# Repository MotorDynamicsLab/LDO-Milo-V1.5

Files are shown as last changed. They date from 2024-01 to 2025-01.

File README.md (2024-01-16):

# LDO Milo V1.5 Kit
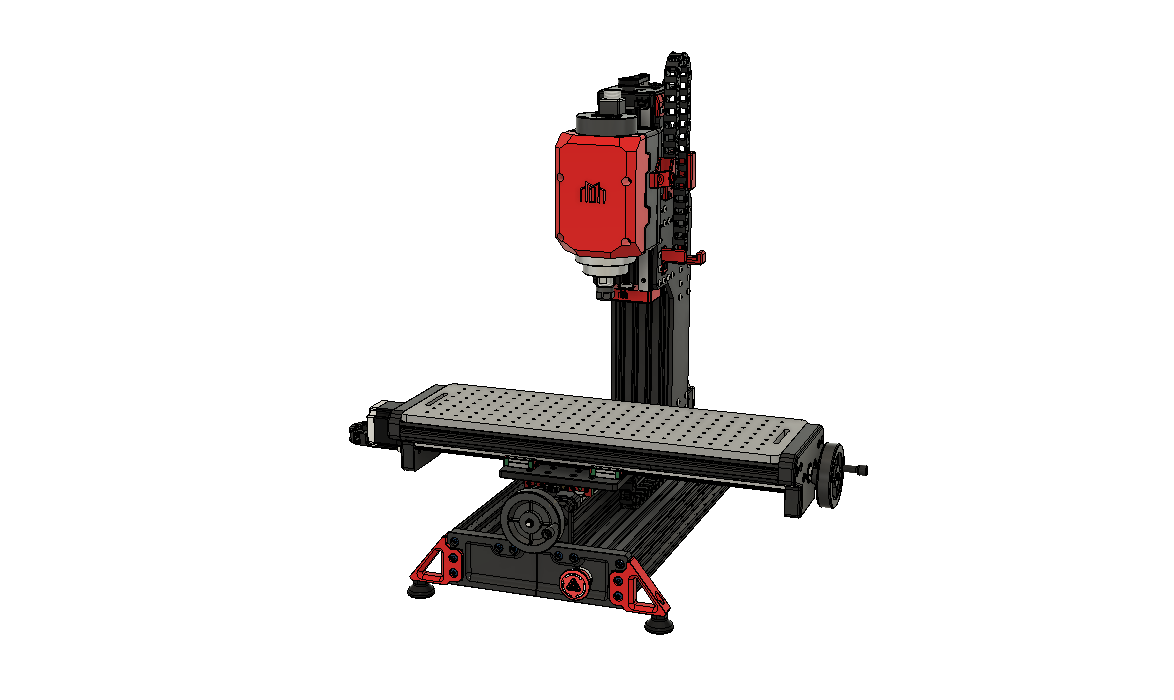
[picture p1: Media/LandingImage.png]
Banner landing image
  

This repository contains supplementary information/configuration/3d models for the LDO Milo V1.5 Kit.

We would thank the Millennium Machines Development team for all their hard work in bringing this open source CNC mill to the community. The github repository for Milo V1.5 can be found [here](https://github.com/MillenniumMachines/Milo-v1.5)  

This repo contains both original and derivative works from the Milo V1.5 project, which is licensed GPLv3. This repo therefore is also licensed under the terms of the GNU Public License, verison 3.

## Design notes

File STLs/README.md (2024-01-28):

Please refer to [PRINTED_PARTS.md](PRINTED_PARTS.md) for the full list of printed parts required for our LDO Milo Kit

## Inlet Skirt 1.0mm
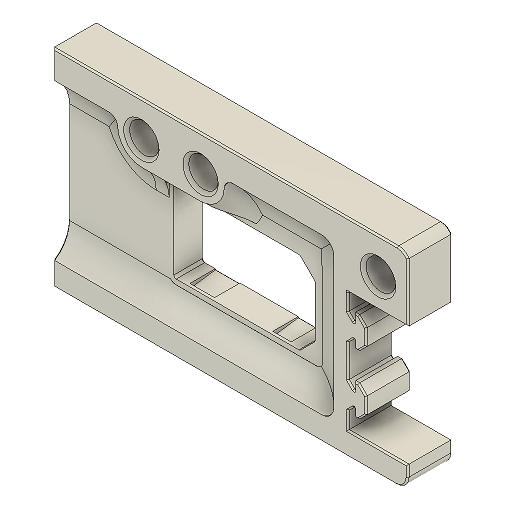
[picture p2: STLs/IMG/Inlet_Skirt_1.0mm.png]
  
This part replaces the `plug_panel` part from the official [Milo V1.5 repo](https://github.com/MillenniumMachines/Milo-v1.5/tree/main/STL%20Files). It adapts specifically to 1.0mm AC inlets for a better fit.

## Fly CDY V3 Mount
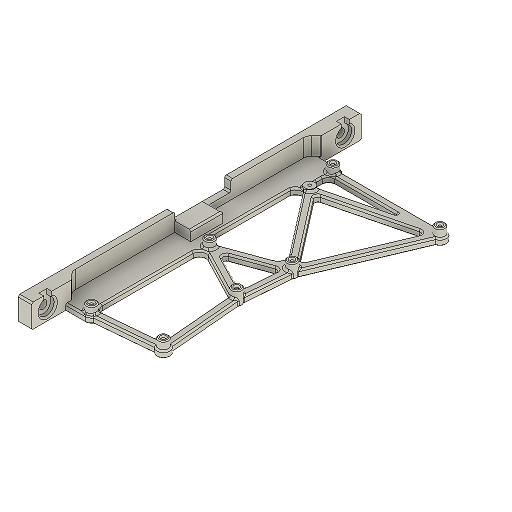
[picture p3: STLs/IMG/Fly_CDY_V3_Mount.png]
  
This is an LDO designed mount for the FLY CDY V3 mainboard provided in the kit. It replaces the original printed part and allows for easy insertion of the SD card. 

## I/O Expander Mount
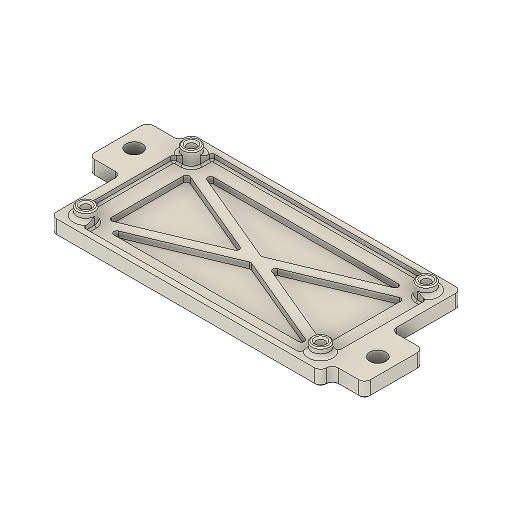
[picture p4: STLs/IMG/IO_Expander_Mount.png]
  
This is a printed mount for the LDO I/O expansion board included in the kit. The expansion board allows the mainboard to control the spindle VFD.

## I/O Expander Mount (For DIN Rails)
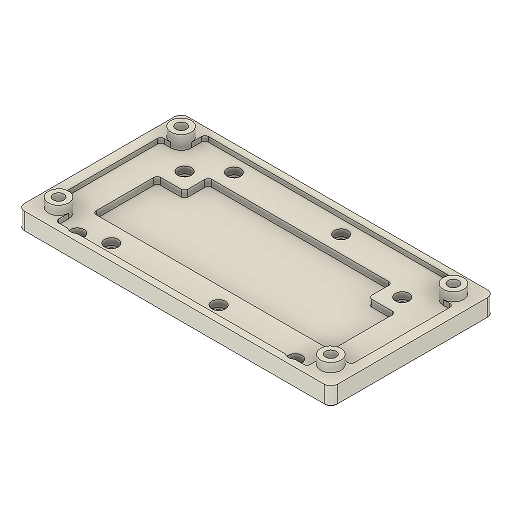
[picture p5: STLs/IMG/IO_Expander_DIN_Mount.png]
  
This printed part is for the same I/O expansion board as described above, it is specifically used for mounting on DIN rails for the CASA mod.

## LMF350-UH PSU Mount
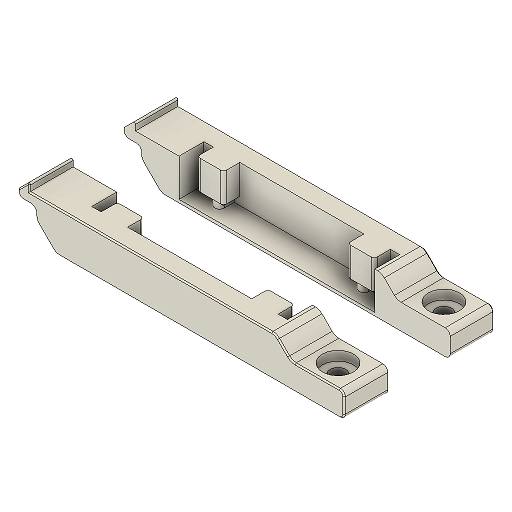
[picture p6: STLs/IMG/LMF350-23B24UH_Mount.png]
  
The LMF350-UH series compact power supplied in the kit uses these mounting brackets. 

## LDO Handwheel
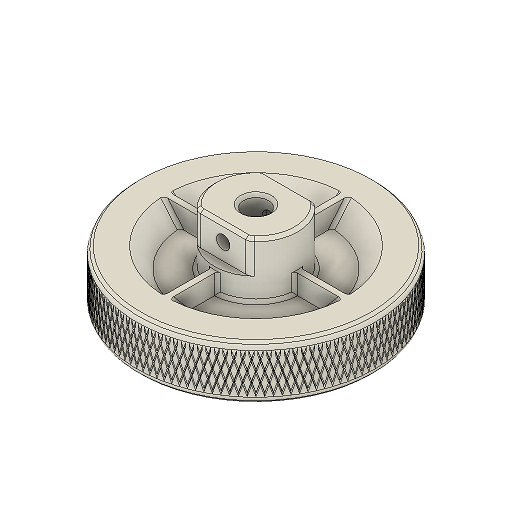
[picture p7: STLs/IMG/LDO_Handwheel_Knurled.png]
  
This is an optional handle wheel design which features knurling. 

## LDO Handwheel (Smooth)
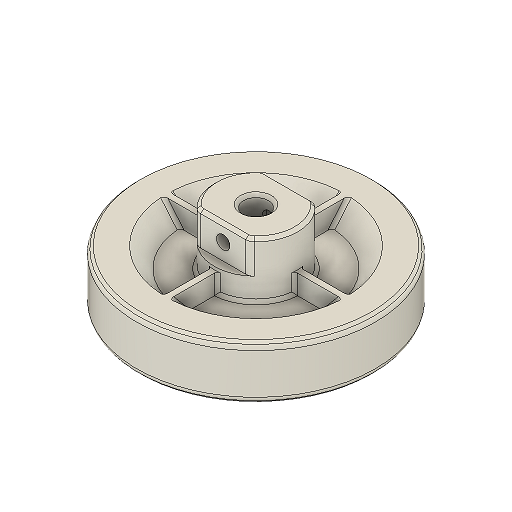
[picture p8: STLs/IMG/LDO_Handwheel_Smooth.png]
  
This is the same handwheel as above but omits knurling.

## X Motor Mount
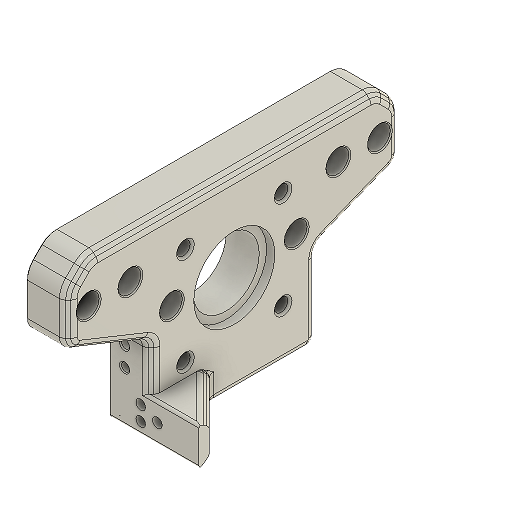
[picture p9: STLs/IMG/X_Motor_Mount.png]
  
This X Motor mount features a small tab that prevents the X drag chain from flopping.

## FMJ Z Chain Backer
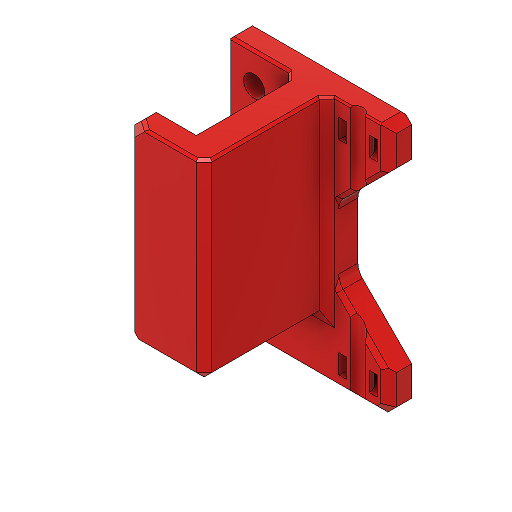
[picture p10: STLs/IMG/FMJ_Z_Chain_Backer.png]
  
This drag chain backer mounts on the FMJ plate. It also features anchor points for cable ties.

## Z Drag Chain Mount B
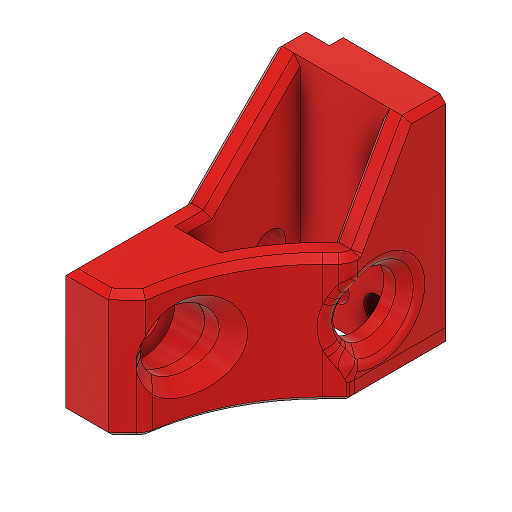
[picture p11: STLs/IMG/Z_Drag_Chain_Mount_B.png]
  
This drag chain mount replaces the original Z Drag Chain Mount B, it helps prevent flopping.

## Z Top Cable Tie Anchor
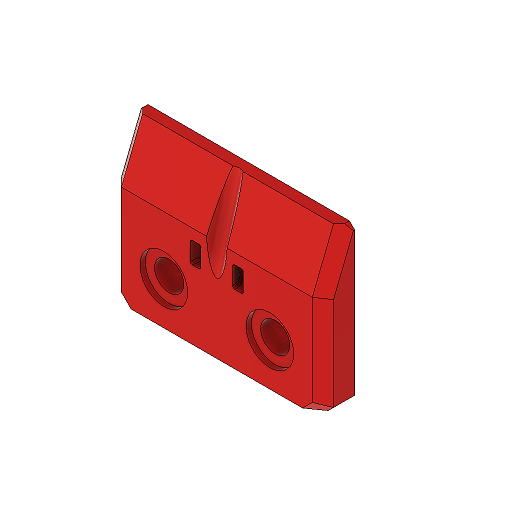
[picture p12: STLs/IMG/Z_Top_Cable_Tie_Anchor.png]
  
This optional printed part adds a cable tie anchor at the top of the main column.

## Rear Cable Cover
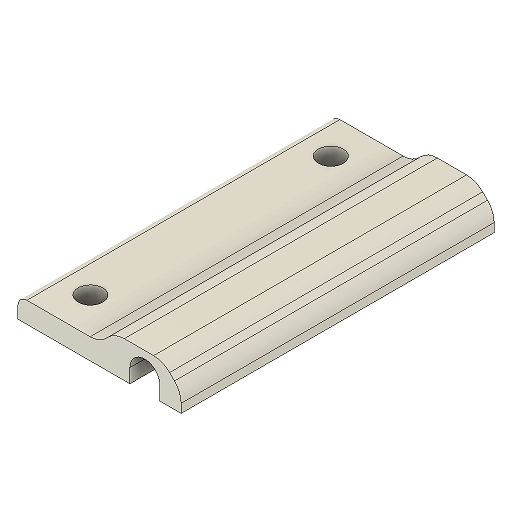
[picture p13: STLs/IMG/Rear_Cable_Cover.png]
  
This optional printed part helps hold down the X and Y cables onto the electronics table.

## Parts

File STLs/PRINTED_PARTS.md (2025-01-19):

# Printed Parts List
This repo contains all of the parts required for the LDO kit.  We have excluded some parts from the original repository that are not needed for our kit and
have added or modified parts as denoted in the "LDO Version" column.  Parts with multiple variations are interchangeable and only one version is needed.

## Print Quality (Strength)
These setting assume that parts will be printed with a 0.4mm nozzle and 0.2mm layer height and result in a 1.6mm wall thickness

- Infill 40%
- Wall Loops 4
- Top/Bottom Layers 8

## Filename Convention

Filenames with one of the following denotes a recommended filament color otherwise use your primary color 
- [a] - accent
- [o] - opaque 
- [c] - clear

(Note: This repo may not use all of these)
            
Filenames with a [v] denote a part has multiple variations
- [v] - variation

Filenames with a [##] denotes specific wall thickness instead of the default
- i.e. [24] 2.4mm thickness with a 0.4 mm nozzle and 0.2 layer height
- Walls Loops 2.4/0.4 = 6
- Top/Bottom Layers 2.4/0.2 = 12

Filenames will include x# denotes how many copies you will need
- i.e. Test x3.stl will require 3 copies
%5Ba%5D
Filenames with "LDO" denotes that we have modified the original part or it's specific to the LDO kit
# Electronics Table
|File|Directory|Qty|Color|Strength|LDO Version|Variations|
|---|---|---|---|---|---|---|
|<a href="Electronics Table/Cable Channel Cover x1.stl">Cable Channel Cover x1.stl</a>|Electronics Table|1|Primary|1.6mm|||
|<a href="Electronics Table/Cable Channel x1.stl">Cable Channel x1.stl</a>|Electronics Table|1|Primary|1.6mm|||
|<a href="Electronics Table/IO Expander DIN Mount  x1_LDO.stl">IO Expander DIN Mount  x1_LDO.stl</a>|Electronics Table|1|Primary|1.6mm|X||
|<a href="Electronics Table/IO Expander Mount  x1_LDO.stl">IO Expander Mount  x1_LDO.stl</a>|Electronics Table|1|Primary|1.6mm|X||
|<a href="Electronics Table/Mainboard Mount x1_LDO.stl">Mainboard Mount x1_LDO.stl</a>|Electronics Table|1|Primary|1.6mm|X||
|<a href="Electronics Table/PSU Mounting Brackets  x1_LDO.stl">PSU Mounting Brackets  x1_LDO.stl</a>|Electronics Table|1|Primary|1.6mm|X||
|<a href="Electronics Table/Rear Skirt A x1.stl">Rear Skirt A x1.stl</a>|Electronics Table|1|Primary|1.6mm|||
|<a href="Electronics Table/Rear Skirt B x1.stl">Rear Skirt B x1.stl</a>|Electronics Table|1|Primary|1.6mm|||
|<a href="Electronics Table/Skirt Front A Solid x1.stl">Skirt Front A Solid x1.stl</a>|Electronics Table|1|Primary|1.6mm|||
|<a href="Electronics Table/Skirt Front B E-Stop x1.stl">Skirt Front B E-Stop x1.stl</a>|Electronics Table|1|Primary|1.6mm|||
|<a href="Electronics Table/TPU Feet x4.stl">TPU Feet x4.stl</a>|Electronics Table|1|Primary|1.6mm|||
|<a href="Electronics Table/WAGO Mount x1_LDO.stl">WAGO Mount x1_LDO.stl</a>|Electronics Table|1|Primary|1.6mm|X||
|<a href="Electronics Table/%5Ba%5D Table Bolt Down Bracket A x2_LDO.stl">[a] Table Bolt Down Bracket A x2_LDO.stl</a>|Electronics Table|2|Accent|1.6mm|X||
|<a href="Electronics Table/%5Ba%5D Table Bolt Down Bracket B x2_LDO.stl">[a] Table Bolt Down Bracket B x2_LDO.stl</a>|Electronics Table|2|Accent|1.6mm|X||
# Minimill Main
|File|Directory|Qty|Color|Strength|LDO Version|Variations|
|---|---|---|---|---|---|---|
|<a href="Minimill Main/Continental Breakfast Mount x2_LDO.stl">Continental Breakfast Mount x2_LDO.stl</a>|Minimill Main|2|Primary|1.6mm|X||
|<a href="Minimill Main/Millenium Maker Coin.stl">Millenium Maker Coin.stl</a>|Minimill Main|1|Primary|1.6mm|||
|<a href="Minimill Main/Toolsetter x1_LDO.stl">Toolsetter x1_LDO.stl</a>|Minimill Main|1|Primary|1.6mm|X||
# Cable Chain Mounts
|File|Directory|Qty|Color|Strength|LDO Version|Variations|
|---|---|---|---|---|---|---|
|<a href="Minimill Main/Cable Chain Mounts/Rear Cable Cover x1_LDO.stl">Rear Cable Cover x1_LDO.stl</a>|Minimill Main/Cable Chain Mounts|1|Primary|1.6mm|X||
|<a href="Minimill Main/Cable Chain Mounts/%5Ba%5D XY Drag Chain Transition x1.stl">[a] XY Drag Chain Transition x1.stl</a>|Minimill Main/Cable Chain Mounts|1|Accent|1.6mm||| [a] XY Drag Chain Transition x1.stl
|<a href="Minimill Main/Cable Chain Mounts/%5Ba%5D Y Drag Chain Mount x1.stl">[a] Y Drag Chain Mount x1.stl</a>|Minimill Main/Cable Chain Mounts|1|Accent|1.6mm|||
|<a href="Minimill Main/Cable Chain Mounts/%5Ba%5D Z Axis Cable Chain Backer x1_LDO.stl">[a] Z Axis Cable Chain Backer x1_LDO.stl</a>|Minimill Main/Cable Chain Mounts|1|Accent|1.6mm|X||
|<a href="Minimill Main/Cable Chain Mounts/%5Ba%5D Z Cable Redirect Hook x1.stl">[a] Z Cable Redirect Hook x1.stl</a>|Minimill Main/Cable Chain Mounts|1|Accent|1.6mm|||
|<a href="Minimill Main/Cable Chain Mounts/%5Ba%5D Z Drag Chain Mount A x1_LDO.stl">[a] Z Drag Chain Mount A x1_LDO.stl</a>|Minimill Main/Cable Chain Mounts|1|Accent|1.6mm|X||
|<a href="Minimill Main/Cable Chain Mounts/%5Ba%5D Z Drag Chain Mount B x1_LDO.stl">[a] Z Drag Chain Mount B x1_LDO.stl</a>|Minimill Main/Cable Chain Mounts|1|Accent|1.6mm|X||
|<a href="Minimill Main/Cable Chain Mounts/%5Ba%5D Z Top Cable Tie Anchor_LDO.stl">[a] Z Top Cable Tie Anchor_LDO.stl</a>|Minimill Main/Cable Chain Mounts|1|Accent|1.6mm|X||
# Hand Wheels
|File|Directory|Qty|Color|Strength|LDO Version|Variations|
|---|---|---|---|---|---|---|
|<a href="Minimill Main/Hand Wheels/Handwheel Handle x2.stl">Handwheel Handle x2.stl</a>|Minimill Main/Hand Wheels|1|Primary|1.6mm|||
|<a href="Minimill Main/Hand Wheels/%5Bv%5D Handwheel Body Knurled x2_LDO.stl">[v] Handwheel Body Knurled x2_LDO.stl</a>|Minimill Main/Hand Wheels|2|Primary|1.6mm|X|X|
|<a href="Minimill Main/Hand Wheels/%5Bv%5D Handwheel Body x2_LDO.stl">[v] Handwheel Body x2_LDO.stl</a>|Minimill Main/Hand Wheels|2|Primary|1.6mm|X|X|
# Main Column
|File|Directory|Qty|Color|Strength|LDO Version|Variations|
|---|---|---|---|---|---|---|
|<a href="Minimill Main/Main Column/Ballast Box x1.stl">Ballast Box x1.stl</a>|Minimill Main/Main Column|1|Primary|1.6mm|||
|<a href="Minimill Main/Main Column/Ballast Cap x1.stl">Ballast Cap x1.stl</a>|Minimill Main/Main Column|1|Primary|1.6mm|||
# Spindle Mount
|File|Directory|Qty|Color|Strength|LDO Version|Variations|
|---|---|---|---|---|---|---|
|<a href="Minimill Main/Spindle Mount/Logo Insert x1.stl">Logo Insert x1.stl</a>|Minimill Main/Spindle Mount|1|Primary|1.6mm|||
|<a href="Minimill Main/Spindle Mount/%5B24%5D Spindle Mount 80mm Part B x1_LDO.stl">[24] Spindle Mount 80mm Part B x1_LDO.stl</a>|Minimill Main/Spindle Mount|1|Primary|2.4mm|X||
|<a href="Minimill Main/Spindle Mount/%5Ba%5D%5B24%5D Spindle Mount 80mm Part A x1_LDO.stl">[a][24] Spindle Mount 80mm Part A x1_LDO.stl</a>|Minimill Main/Spindle Mount|1|Accent|2.4mm|X||
# X Axis STLs
|File|Directory|Qty|Color|Strength|LDO Version|Variations|
|---|---|---|---|---|---|---|
|<a href="Minimill Main/X Axis STLs/X Axis Anti Backlash Nut x1_LDO.stl">X Axis Anti Backlash Nut x1_LDO.stl</a>|Minimill Main/X Axis STLs|1|Primary|1.6mm|X||
|<a href="Minimill Main/X Axis STLs/X Axis Bearing Block x1_LDO.stl">X Axis Bearing Block x1_LDO.stl</a>|Minimill Main/X Axis STLs|1|Primary|1.6mm|X||
|<a href="Minimill Main/X Axis STLs/X Axis Motor Mount x1_LDO.stl">X Axis Motor Mount x1_LDO.stl</a>|Minimill Main/X Axis STLs|1|Primary|1.6mm|X||
|<a href="Minimill Main/X Axis STLs/X Axis Table Support Centre x2_LDO.stl">X Axis Table Support Centre x2_LDO.stl</a>|Minimill Main/X Axis STLs|2|Primary|1.6mm|X||
|<a href="Minimill Main/X Axis STLs/X Axis Table Support Ends x4_LDO.stl">X Axis Table Support Ends x4_LDO.stl</a>|Minimill Main/X Axis STLs|4|Primary|1.6mm|X||
# Y Axis STLs
|File|Directory|Qty|Color|Strength|LDO Version|Variations|
|---|---|---|---|---|---|---|
|<a href="Minimill Main/Y Axis STLs/Y Axis Anti Backlash Nut x1_LDO.stl">Y Axis Anti Backlash Nut x1_LDO.stl</a>|Minimill Main/Y Axis STLs|1|Primary|1.6mm|X||
|<a href="Minimill Main/Y Axis STLs/Y Axis Bearing Block x1_LDO.stl">Y Axis Bearing Block x1_LDO.stl</a>|Minimill Main/Y Axis STLs|1|Primary|1.6mm|X||
|<a href="Minimill Main/Y Axis STLs/Y Axis Motor Mount x1_LDO.stl">Y Axis Motor Mount x1_LDO.stl</a>|Minimill Main/Y Axis STLs|1|Primary|1.6mm|X||
# Z Axis STLs
|File|Directory|Qty|Color|Strength|LDO Version|Variations|
|---|---|---|---|---|---|---|
|<a href="Minimill Main/Z Axis STLs/Z Axis Anti Backlash Nut x1_LDO.stl">Z Axis Anti Backlash Nut x1_LDO.stl</a>|Minimill Main/Z Axis STLs|1|Primary|1.6mm|X||
|<a href="Minimill Main/Z Axis STLs/Z Motor Mount x1_LDO.stl">Z Motor Mount x1_LDO.stl</a>|Minimill Main/Z Axis STLs|1|Primary|1.6mm|X||
|<a href="Minimill Main/Z Axis STLs/%5Ba%5D Z Axis Bearing Block x1_LDO.stl">[a] Z Axis Bearing Block x1_LDO.stl</a>|Minimill Main/Z Axis STLs|1|Accent|1.6mm|X||
# Tools
|File|Directory|Qty|Color|Strength|LDO Version|Variations|
|---|---|---|---|---|---|---|
|<a href="Tools/Dummy Rail.stl">Dummy Rail.stl</a>|Tools|1|Primary|1.6mm|||
|<a href="Tools/Rail Alignment Guide.stl">Rail Alignment Guide.stl</a>|Tools|1|Primary|1.6mm|||
|<a href="Tools/Rail Grease Packing Tool.stl">Rail Grease Packing Tool.stl</a>|Tools|1|Primary|1.6mm|||

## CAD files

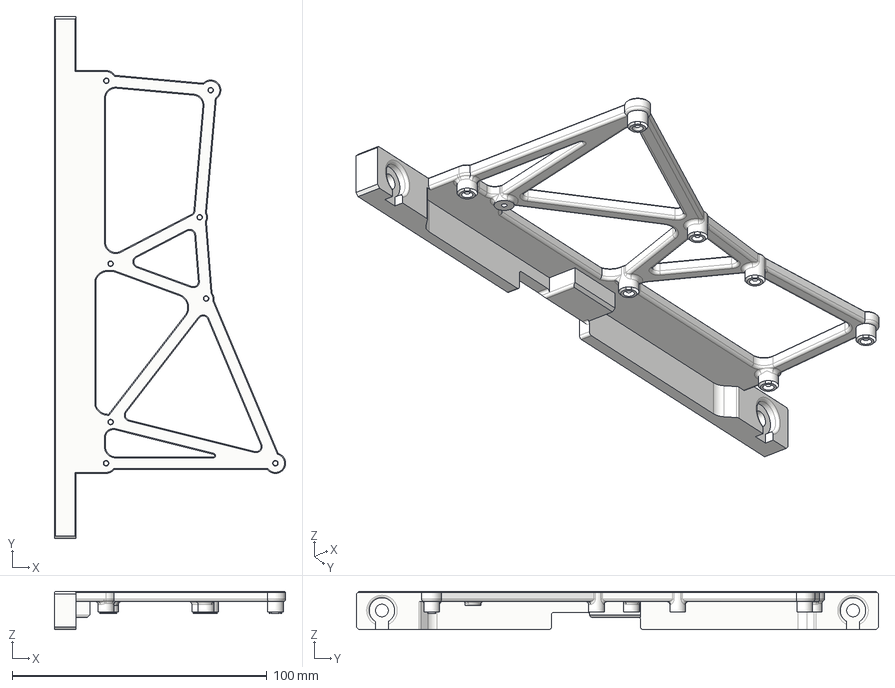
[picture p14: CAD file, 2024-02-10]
STLs/Electronics Table/Mainboard Mount x1_LDO.step
90.8 x 205.0 x 15.0 mm

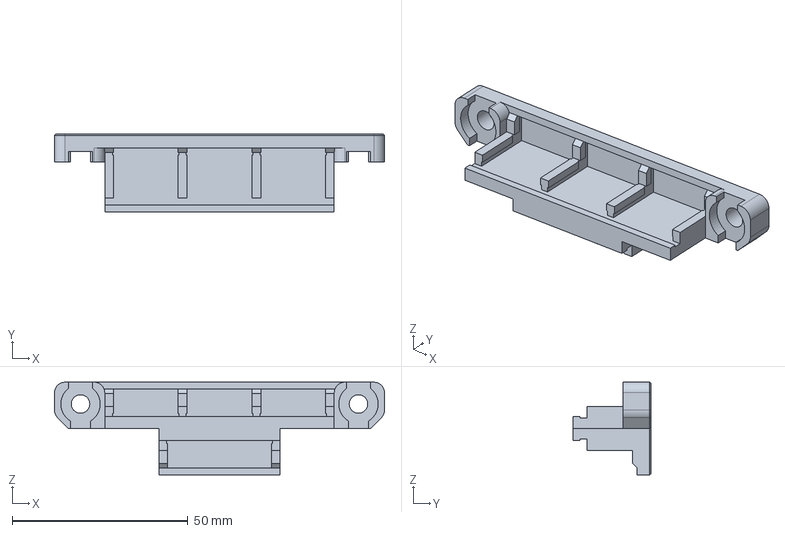
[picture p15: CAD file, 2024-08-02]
STLs/Electronics Table/WAGO Mount x1_LDO.step
93.8 x 22.3 x 26.3 mm

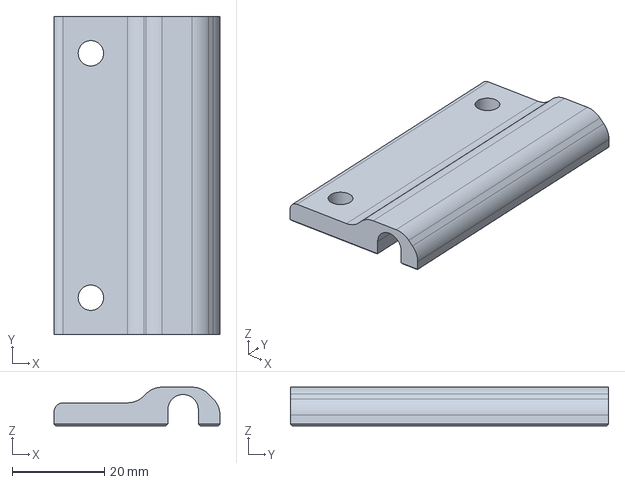
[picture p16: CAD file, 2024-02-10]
STLs/Minimill Main/Cable Chain Mounts/Rear Cable Cover x1_LDO.step
36.0 x 69.0 x 8.40 mm

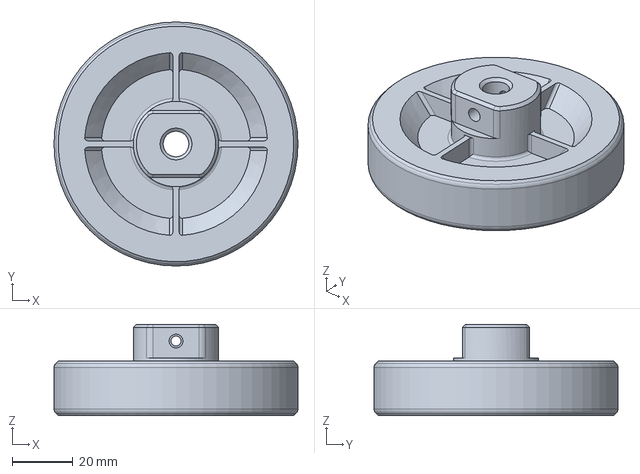
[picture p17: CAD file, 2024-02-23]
STLs/Minimill Main/Hand Wheels/[v] Handwheel Body x2_LDO.step
80.0 x 80.0 x 30.0 mm

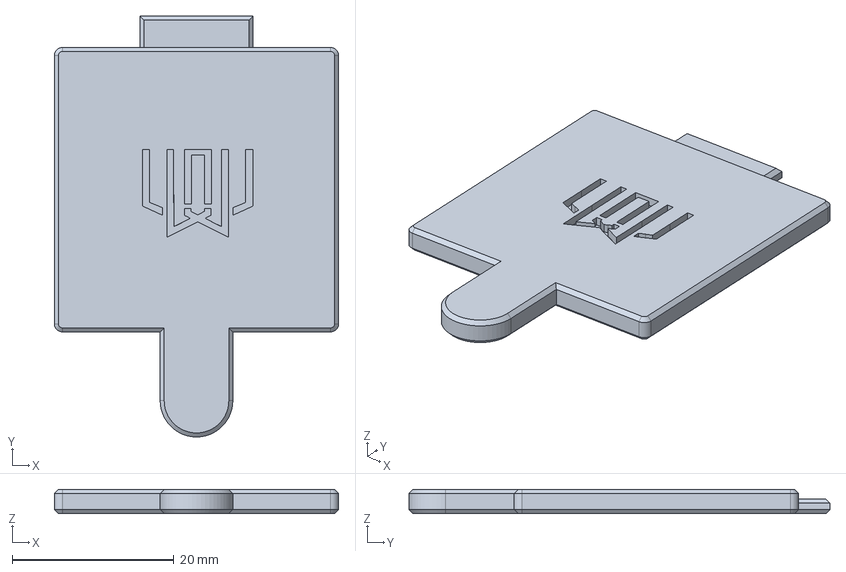
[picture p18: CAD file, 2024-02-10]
STLs/Minimill Main/Main Column/Ballast Cap x1.step
35.2 x 52.1 x 3.00 mm

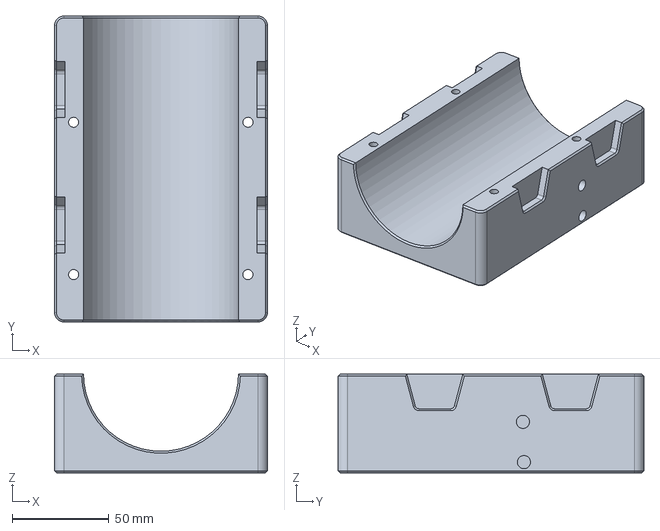
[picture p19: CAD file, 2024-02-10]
STLs/Minimill Main/Spindle Mount/[24] Spindle Mount 80mm Part B x1_LDO.step
110.0 x 158.0 x 50.9 mm

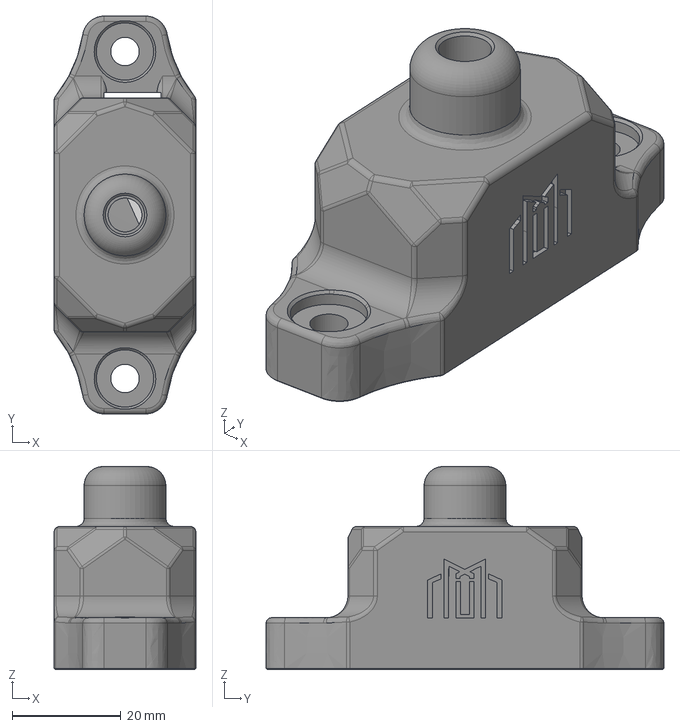
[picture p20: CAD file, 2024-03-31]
STLs/Minimill Main/Toolsetter x1_LDO.step
26.0 x 73.0 x 37.3 mm

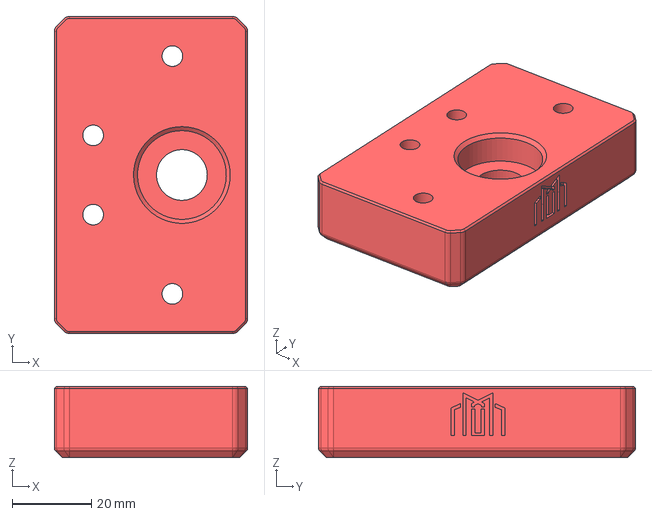
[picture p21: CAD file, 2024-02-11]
STLs/Minimill Main/Z Axis STLs/[a] Z Axis Bearing Block x1_LDO.step
48.8 x 80.0 x 18.0 mm

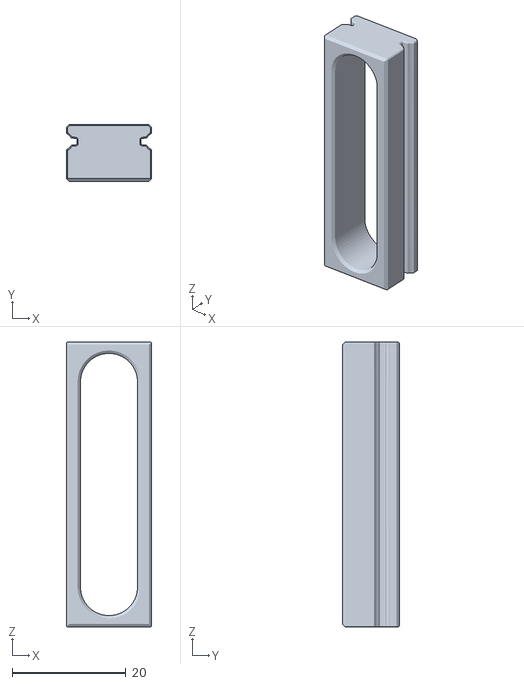
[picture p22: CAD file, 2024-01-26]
STLs/Tools/Dummy Rail.stl
15.0 x 10.0 x 50.0

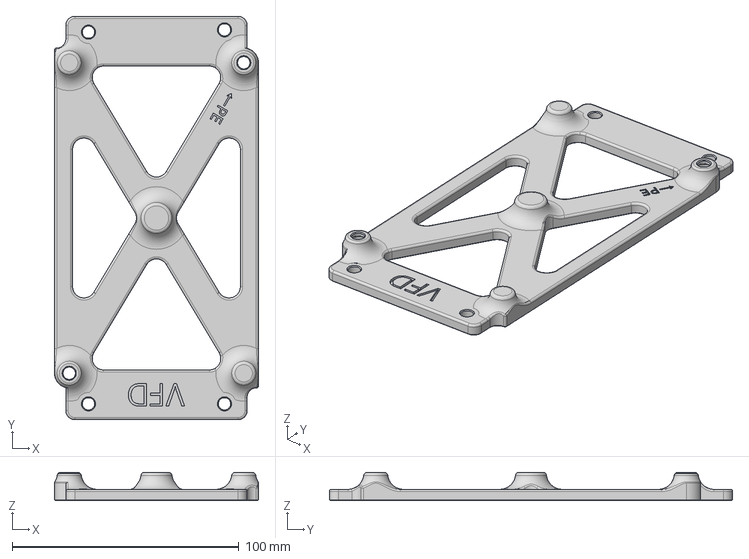
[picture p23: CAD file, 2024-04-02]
STLs/Electronics Table/VFD Mount 110v.step
90.0 x 178.0 x 12.5 mm

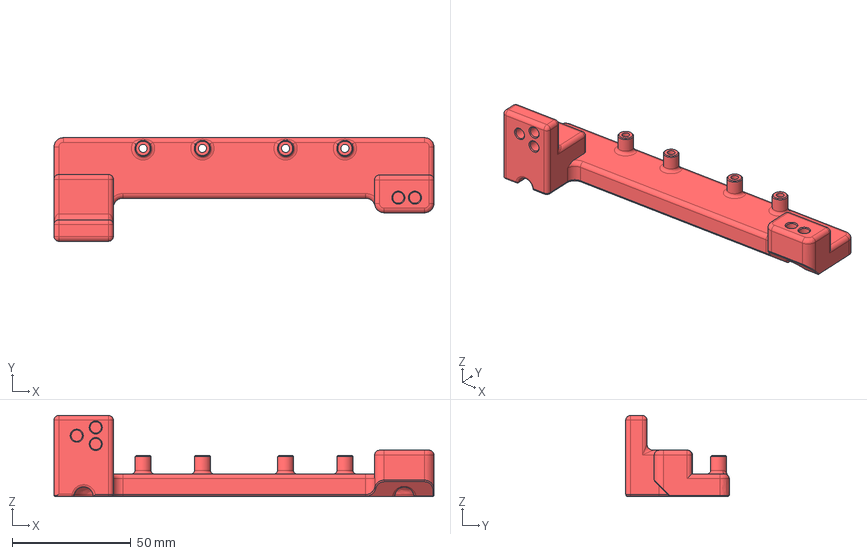
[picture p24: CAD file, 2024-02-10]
STLs/Minimill Main/Cable Chain Mounts/[a] XY Drag Chain Transition x1.step
160.0 x 43.6 x 34.1 mm

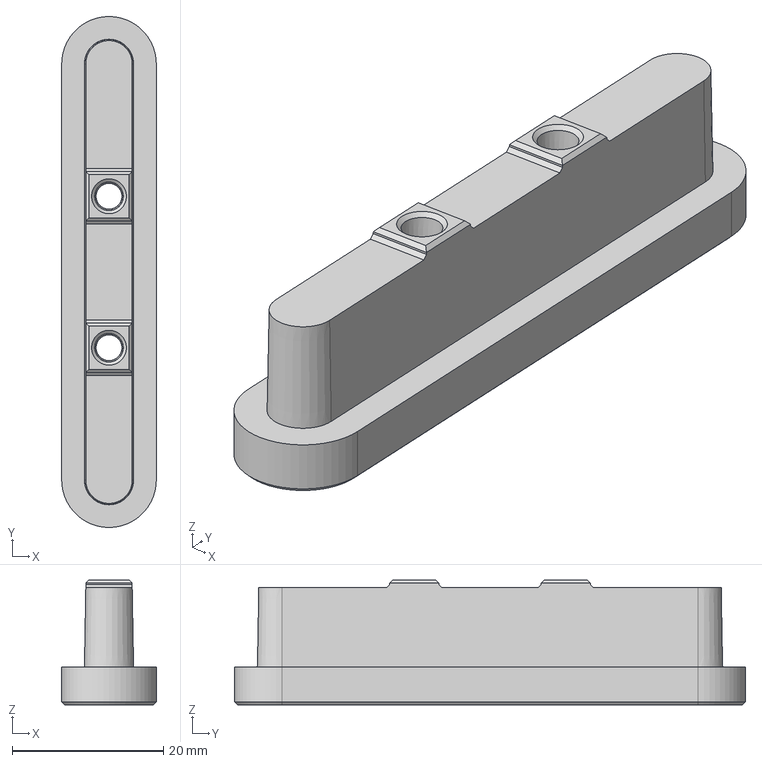
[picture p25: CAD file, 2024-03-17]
STLs/Minimill Main/Continental Breakfast Mount x2_LDO.step
12.5 x 67.5 x 16.5 mm

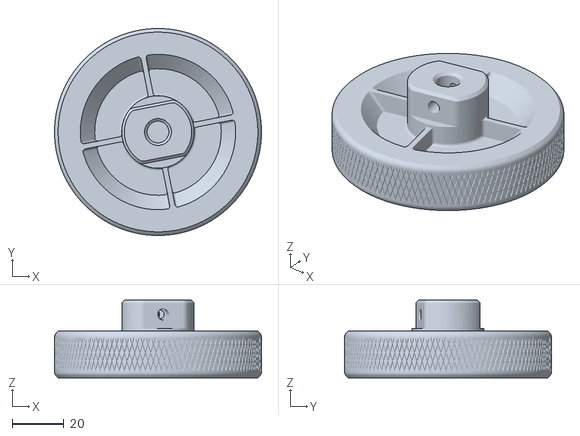
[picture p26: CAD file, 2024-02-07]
STLs/Minimill Main/Hand Wheels/[v] Handwheel Body Knurled x2_LDO.stl
80.0 x 80.0 x 30.0

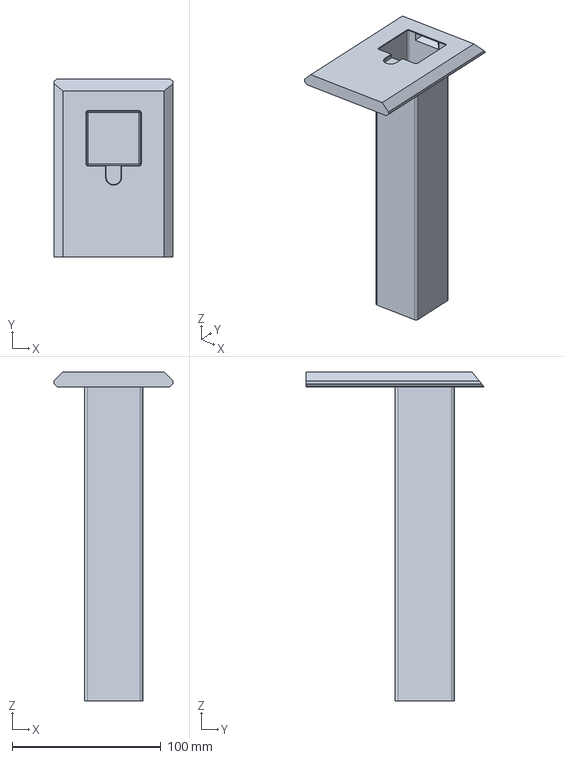
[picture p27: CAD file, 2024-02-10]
STLs/Minimill Main/Main Column/Ballast Box x1.step
80.0 x 119.9 x 221.3 mm

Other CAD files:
STLs/Minimill Main/Spindle Mount/Logo Insert x1.step
STLs/Minimill Main/X Axis STLs/X Axis Bearing Block x1_LDO.step
STLs/Minimill Main/Y Axis STLs/Y Axis Bearing Block x1_LDO.step
STLs/Tools/Rail Alignment Guide.stl
STLs/Electronics Table/Cable Channel Cover x1.stl
STLs/Electronics Table/IO Expander DIN Mount x1_LDO.step
STLs/Electronics Table/IO Expander DIN Mount x1_LDO.stl
STLs/Electronics Table/IO Expander Mount x1_LDO.step
STLs/Electronics Table/IO Expander Mount x1_LDO.stl
STLs/Electronics Table/Mainboard Mount x1_LDO.stl
STLs/Electronics Table/PSU Mounting Brackets x1_LDO.step
STLs/Electronics Table/PSU Mounting Brackets x1_LDO.stl
STLs/Electronics Table/Rear Skirt A x1.step
STLs/Electronics Table/Rear Skirt A x1.stl
STLs/Electronics Table/Rear Skirt B x1.step
STLs/Electronics Table/Rear Skirt B x1.stl
STLs/Electronics Table/Skirt Front A Solid x1.step
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

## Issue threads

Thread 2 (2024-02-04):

File not found

atrueresistance, 2024-02-04:
[[a] Z Axis Cable Cover x1_LDO.stl](https://github.com/MotorDynamicsLab/LDO-Milo-V1.5/blob/master/STLs/Minimill%20Main/Cable%20Chain%20Mounts/[a]%20Z%20Axis%20Cable%20Cover%20x1_LDO.stl)	Minimill Main/Cable Chain Mounts

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

camerony, 2024-02-06:
This is fixed, the file was renamed.

Closed 2024-02-06.

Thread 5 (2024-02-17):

PSU Mounting Brackets regression

8000ff, 2024-02-17:
The [PSU Mounting Brackets](STLs/Electronics Table/PSU Mounting Brackets  x1_LDO.stl) were reverted, these ones do not fit the base, the right ones hook into the 2040 extrusion.

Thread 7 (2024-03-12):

Y Axis Anti Backlash Nut Issue

vvviiimmm, 2024-03-12:
Y backlash nut holes are not symmetric and have a floating region resulting in a defective print
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

ednation05, 2024-03-20:
I second this request.  And there are other issues you can fix on this part.
Details in image
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

benvanik, 2024-04-09:
Also noticing slicing issues with this (haven't yet tried printing, but it's sus).

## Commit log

2023-11-22 add mounts for IO expander and LMF350-23B24UH PSU
    [IO_Expander_DIN_Mount.stl, IO_Expander_Mount.stl, LMF350-23B24UH_Mount.stl]
2023-11-22 change LMF350-23B24UH_Mount.stl to not require any M3 screws
    [LMF350-23B24UH_Mount.stl]
2023-11-22 reorient some stl files
    [Fly_CDY_V3_Mount.stl, LMF350-23B24UH_Mount.stl]
2023-11-24 remove unused support that caused interference in Fly_CDY_V3_Mount.stl
    [Fly_CDY_V3_Mount.stl]
2024-01-16 fix orientation of Fly_CDY_V3_Mount.stl
    [Fly_CDY_V3_Mount.stl]
2024-01-16 add FMJ Z Chain Backer
    [[a]_FMJ_Z_Chain_Backer.stl]
2024-01-16 add inlet skirt 1.0mm and LDO handwheel
    [Inlet_Skirt_1.0mm.stl, LDO_Handwheel_Knurled.stl, LDO_Handwheel_Smooth.stl]
2024-01-16 add cable covers and Z cable management parts
    [Rear_Cable_Cover.stl, [a]_Z_Drag_Chain_Mount_B.stl, [a]_Z_Top_Cable_Tie_Anchor.stl]
2024-01-16 change colour of PSU mount image
2024-01-16 add X Motor Mount
    [X_Motor_Mount.stl]
2024-01-16 add preliminary README.md to STL/ directory
2024-01-16 resize Inlet_Skirt_1.0mm.png
2024-01-16 resize all stl images
2024-01-21 LDO Versions
    [Ballast Box x1.stl, Ballast Cap x1.stl, Cable Channel Cover x1.stl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]
2024-01-28 Update [a][24] Spindle Mount 80mm Part A x1.stl
    [[a][24] Spindle Mount 80mm Part A x1.stl]
2024-01-29 Update [24] Spindle Mount 80mm Part B x1.stl
    [[24] Spindle Mount 80mm Part B x1.stl]
2024-01-29 Update Ballast Box x1.stl
    [Ballast Box x1.stl]
2024-02-03 Update [24] Spindle Mount 80mm Part B x1.stl
    Adjust heatinsert hole size to 6.8mm
    [[24] Spindle Mount 80mm Part B x1.stl]
2024-02-04 rename Z axis Cable Cover to Rear Cable Cover
    [Rear Cable Cover x1_LDO.stl]
2024-02-07 Changed M3 Heatset Holes to 4.7mm
    [X Axis Anti Backlash Nut x1_LDO.stl, X Axis Motor Mount x1_LDO.stl, Y Axis Anti Backlash Nut x1_LDO.stl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]
2024-02-10 STEP and HiRes STLs
    [Ballast Box x1.step, Ballast Box x1.stl, Ballast Cap x1.step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]
2024-02-11 Update Y Axis Bearing Block x1_LDO.stl
    [Y Axis Bearing Block x1_LDO.stl]
2024-02-11 Update [a] Z Axis Bearing Block x1_LDO.step
    [[a] Z Axis Bearing Block x1_LDO.step]
2024-02-12 Update Y Axis Anti Backlash Nut x1_LDO.stl
    [Y Axis Anti Backlash Nut x1_LDO.stl]
2024-02-12 Update holes to 5.2mm
    [Rear Skirt A x1.step, Rear Skirt A x1.stl, Rear Skirt B x1.step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]
2024-02-21 Wrong PSU mount fixed.
    [PSU Mounting Brackets x1_LDO.step, PSU Mounting Brackets x1_LDO.stl]
2024-02-22 Fix Y bearing block crosshatch
    [Y Axis Bearing Block x1_LDO.step, Y Axis Bearing Block x1_LDO.stl]
2024-02-22 Add 45 deg step for crosshatch
    [X Axis Bearing Block x1_LDO.step, X Axis Bearing Block x1_LDO.stl]
2024-02-23 Removed sacrificial layer
    [[v] Handwheel Body x2_LDO.step]
2024-03-12 Fix tabs for power inlet
    [Rear Skirt B x1.step, Rear Skirt B x1.stl]
2024-03-17 Updated orientation, widen hole for screwhead, and reduce indexing
    [Continental Breakfast Mount x2_LDO.step, Continental Breakfast Mount x2_LDO.stl, PSU Mounting Brackets x1_LDO.stl]
2024-03-27 update wago mount
    [WAGO Mount x1_LDO.f3d, WAGO Mount x1_LDO.stl]
2024-03-31 widen hole for swtich
    [Toolsetter x1_LDO.step, Toolsetter x1_LDO.stl]
2024-04-01 Create VFD Mount 110v.step
    [VFD Mount 110v.step]
2024-04-01 Create VFD Mount 110v.stl
2024-04-01 Update VFD Mount
    [VFD Mount 110v.step]
2024-04-01 Move VFD 110v Mount
    [VFD Mount 110v.step]
2024-06-15 Fix heatset centering
    [Y Axis Anti Backlash Nut x1_LDO.step, Y Axis Anti Backlash Nut x1_LDO.stl]
2024-07-19 Update filename for Spindle Mount
    [[24] Spindle Mount 80mm Part B x1_LDO.step, [24] Spindle Mount 80mm Part B x1_LDO.stl]
2024-08-02 Update WAGO Mount x1_LDO.step
    [WAGO Mount x1_LDO.step]
2024-08-29 Adjusted spacing for heatset
    [X Axis Anti Backlash Nut x1_LDO.step, X Axis Anti Backlash Nut x1_LDO.stl, Y Axis Anti Backlash Nut x1_LDO.step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]
